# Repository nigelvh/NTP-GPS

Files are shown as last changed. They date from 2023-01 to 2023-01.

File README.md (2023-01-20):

# NTP-GPS
Custom GPS Hardware for use with NTP Stratum 1 servers, along with system configuration documentation.

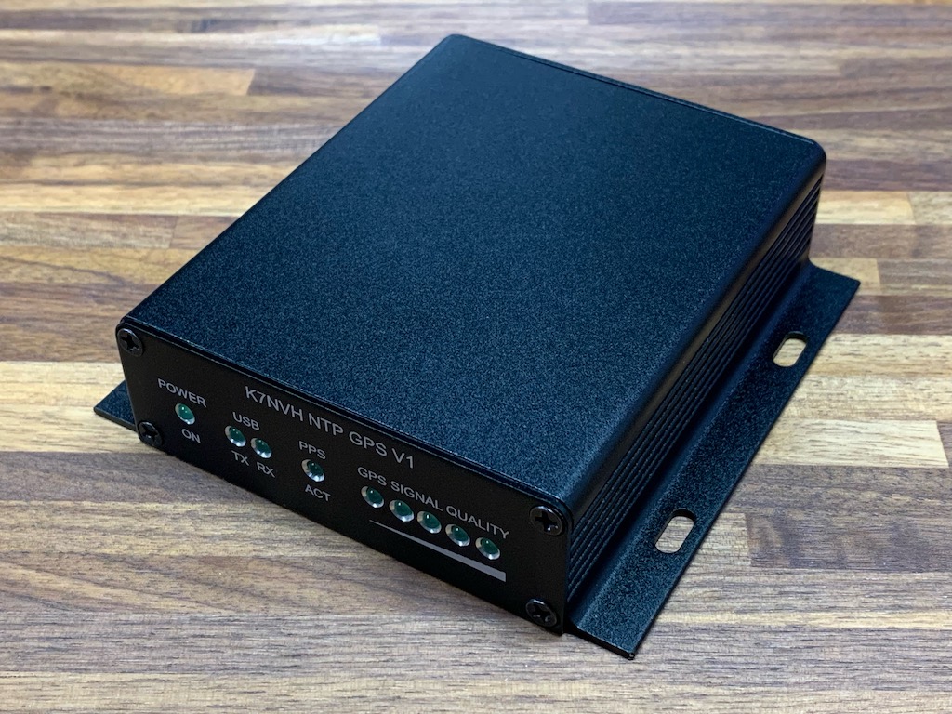
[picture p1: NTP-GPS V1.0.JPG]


## Hardware
The hardware designs for my specific device. There are many GPS options for building a Stratum 1 NTP server. This is just one take on it.

## Firmware
The firmware code and binaries for the device described in the Hardware section. Built in the Arduino IDE to be maximally approachable.

## Software
Configuration guides for setting up NTPd, NTPsec, or Chrony on Ubuntu, Debian, Alma, or Rocky to acquire the PPS signals provided by the GPS and use them to discipline the local clock and act as a Stratum 1 server.

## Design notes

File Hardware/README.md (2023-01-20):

# NTP GPS Hardware
This is a custom piece of hardware for use with stratum 1 NTP servers to provide a simple and flexible way of getting timing data into the NTP daemon of choice.

This is not a wholly unique device, there are other devices that perform similar functions or some subset thereof. It is certainly not the only way to accomplish the task. It was designed as a means to address the most common shortfalls I have seen and for the enjoyment of making it.

This device uses a good quality GPS receiver with precise Pulse Per Second (PPS) output, and exposes both the NMEA data, as well as the PPS signal on the DCD serial line over both USB (less precise timing) as well as RS232 (more precise timing) simultaneously. This is done to provide maximum flexibility to the user's use case. If a hardware serial port is available, use that as it will provide more precise timing. If only USB is available, that is also functional.

Many inexpensive off the shelf GPS receivers do not expose the PPS signals properly on the DCD serial line making precise timing difficult to capture, or expensive time servers are available which are double to many times the cost of this device. This device was designed to fit the middle ground of a quality time source for a use case where an existing server is available, and can be configured per the instructions in the Software folder of this repository.

The schematic and board files have been created in Eagle, though I cannot guarantee how they will load without all the the associated libraries. There are additionally exported images of the schematic and board designs available for reference without using the Eagle software package.

A parts text file has been included to cover some of the more important, or more specific parts for the design. It is not all inclusive (I didn't include the passives for example), but it covers the main components, as well as some useful accessories (cables, antenna, etc).

## Design Choices
### ESP32
The ESP32 was chosen as the microcontroller for this project as it is able to handle three simultaneous hardware UARTs, is reasonably inexpensive, and is easily programmed with the Arduino IDE. In some measures it is overkill for this application, but being inexpensive and easily programmable make it more approachable to more people.

### uBlox MAX-M8 GPS
The uBlox MAX-M8 GPS device was chosen for being a quality GPS chipset, that I am familiar with, and has good timing parameters. The MAX series is not the specifically timing oriented line, however it is more than accurate enough for NTP requirements. It is able to track multiple constellations and has good RF sensitivity. I have fitted it with the associated power circuitry to supply an active GPS antenna which is essential for longer runs of cable, which is likely to be required to span between a rooftop antenna placement and a server located inside a building/datacenter.

### FTDI UART and ST232 Serial Driver
There are microcontroller choices available that could do USB natively, as well as there are other RS232 driver chipsets that may be cheaper. These were chosen for being commonly available, widely used and proven, as well as having the required inputs/outputs to handle the PPS signal over the DCD line, which not all devices support.

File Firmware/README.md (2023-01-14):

# NTP GPS Firmware
This firmware is specific to the device described in the Hardware section. It is a simple Arduino sketch for the ESP32. The only required library is TinyGPSPlus, included in the libraries folder, though this copy does not track upstream and may be (and is likely) very out of date.

## Use one of the compiled binaries
Compiled binaries are available if you don't want to or are unable to use Arduino. They would be flashed to the board using esptool.

## Set up Arduino to work with ESP32
- Open the Arduino preferences pane, and add an `Additional Boards Manager URL` of `https://raw.githubusercontent.com/espressif/arduino-esp32/gh-pages/package_esp32_index.json`.
- Open `Tools -> Board -> Boards Manager`, search for "ESP32", and install the `esp32` package by Espressif Systems.
- Select the ESP32 parameters from the Tools Menu:
    - Board: ESP32 Dev Module
    - Flash Size: 4MB
    - PSRAM: Disabled
    - Port: <your_device_port>

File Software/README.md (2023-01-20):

# System Configuration
Configuration on various systems should look roughly similar, but example steps are provided for the OS's below. We will be using the classic NTPd daemon as the reference, but will also discuss Chrony and NTPsec.

These instructions assume that you have a GPS device that outputs NMEA data, as well as the PPS (Pulse Per Second) signal on the DCD pin of the hardware serial port `/dev/ttyS0`. If your device is on a different port, substitute that port into the configurations. If your device does not output the PPS signal, these instructions are not applicable.

- [Ubuntu 22.04 LTS and Debian 11 Bullseye](#ubuntu-2204-lts-and-debian-11-bullseye)
- [AlmaLinux 9.1 and Rocky Linux 9.1](#almalinux-91-and-rocky-linux-91)
- [Using Chrony](#using-chrony)
- [Using NTPsec](#using-ntpsec)

## Ubuntu 22.04 LTS and Debian 11 Bullseye
### Disable systemd-timesyncd
Ubuntu uses systemd-timesyncd which is a basic SNTP daemon and does not support disciplining or acting as a server for remote clients.
```bash
systemctl disable --now systemd-timesyncd
```
### Install packages
```bash
apt-get update
apt-get install pps-tools gpsd gpsd-clients
```
### Configure GPSd
GPSd will interface with the GPS module to parse the NMEA data for coarse time, and attach to the DCD signal as a PPS source. These data streams will be used to discipline the clock via NTPd's shared memory (SHM) interface.
```bash
curl -o /etc/default/gpsd https://raw.githubusercontent.com/nigelvh/NTP-GPS/main/Software/Files/gpsd.conf
systemctl enable gpsd
systemctl restart gpsd
```
### Verify GPSd is recieving the NMEA data and PPS signal
Use the utility `gpsmon` and look for NMEA sentences scrolling, as well as marks for the PPS offset every second. You might also use this opportunity to check the number of satellites being tracked.
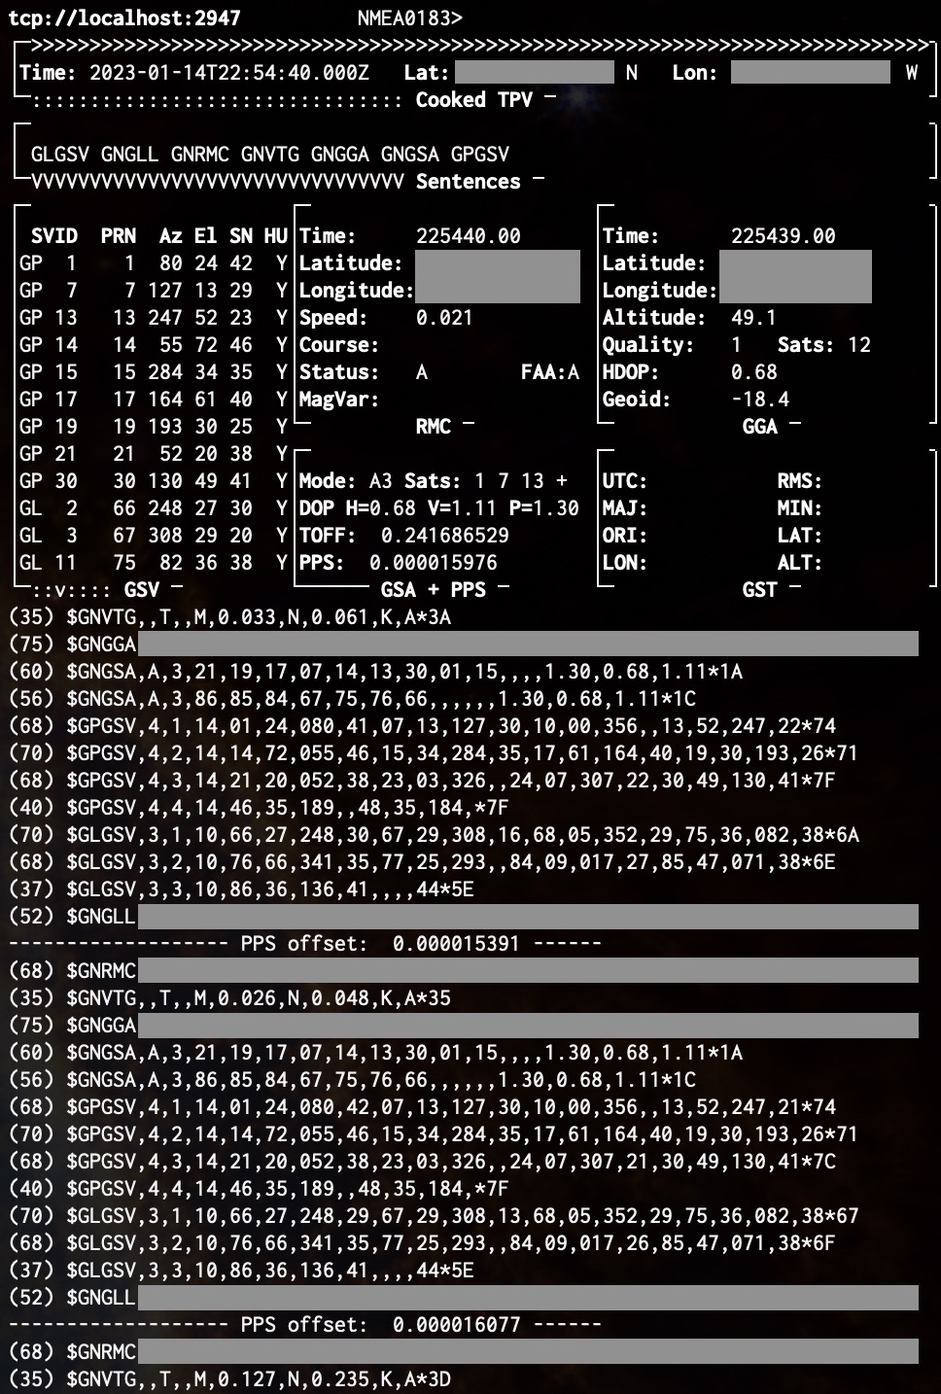
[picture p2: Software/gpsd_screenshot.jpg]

### Install NTPd
```bash
apt-get install ntp
```
### Tweak NTPd AppArmor Profile
The packaged apparmor profile (at the time of this writing) appears to be missing the openssl abstraction from the AppArmor profile, causing AppArmor deny messages to be found in the syslog. Comparing to the AppArmor profile from Debian and NTPsec, we just have to add one line to resolve it. However, the errors don't immediately appear to prevent NTPd from running.
```
test@test:~$ diff -c ~/usr.sbin.ntpd.orig /etc/apparmor.d/usr.sbin.ntpd
*** /home/test/usr.sbin.ntpd.orig	2023-01-14 06:55:32.058055004 +0000
--- /etc/apparmor.d/usr.sbin.ntpd	2023-01-14 06:56:01.138298034 +0000
***************
*** 16,21 ****
--- 16,22 ----
  /usr/sbin/ntpd flags=(attach_disconnected) {
    #include <abstractions/base>
    #include <abstractions/nameservice>
+   #include <abstractions/openssl>
    #include <abstractions/user-tmp>
  
    capability ipc_lock,
```
### Disable dhclient from overriding our NTP configuration
If dhclient is active or has been used on this system, it may override our NTP configuration.
```bash
sed -e "s/, ntp-servers//g" -i.backup /etc/dhcp/dhclient.conf
rm /etc/dhcp/dhclient-exit-hooks.d/ntp
rm /run/ntp.conf.dhcp
```
### Configure NTPd
NTPd will get the coarse time and PPS data via SHMs from GPSd. We'll need to include that in the NTPd configuration. This configuration otherwise is very close to defaults.
```bash
curl -o /etc/ntp.conf https://raw.githubusercontent.com/nigelvh/NTP-GPS/main/Software/Files/ntpd.conf
systemctl enable ntp
systemctl restart ntp
```
### Verify NTPd is getting the data
Query the NTP daemon to see what peers it is using. Look for the '*' next to the SHM(1) PPS peer.
```
test@test:~$ ntpq -c lpeers
     remote           refid      st t when poll reach   delay   offset  jitter
==============================================================================
 0.pool.ntp.org  .POOL.          16 p    -   64    0    0.000   +0.000   0.000
 1.pool.ntp.org  .POOL.          16 p    -   64    0    0.000   +0.000   0.000
*SHM(1)          .PPS.            0 l   40   64  377    0.000   +0.001   0.006
 SHM(0)          .GPS.           15 l   39   64  377    0.000  -242.60   0.727
-vps-7d02b399.vp 131.188.3.220    2 u   59  128  377  142.990   +0.647   1.257
+155.248.196.28  132.163.97.3     2 u   24   64  377   21.639   +1.285   0.580
+172.98.15.136   69.89.207.99     2 u   42   64  377   46.512   +0.900   0.223
-gotoro.hojmark. 97.183.206.88    2 u   48   64  377   58.146   +2.697   3.304
-clock.isc.org   5.200.6.34       3 u   35  128  377   21.762   -3.684   1.021
-66.85.78.80     172.16.23.153    2 u   53  128  377   50.980   -1.350   1.311
```
### Check that NTPd is reachable
Use `ntpdate -d <server_ip>` or configure NTPd on another host to use your new server, and verify that it is reachable. You're done!

## AlmaLinux 9.1 and Rocky Linux 9.1
Alma Linux defaults to using Chrony, so we'll use that as our example config.
### Install Packages
```bash
yum install epel-release
yum install gpsd gpsd-clients
```
### Configure GPSd
GPSd will interface with the GPS module to parse the NMEA data for coarse time, and attach to the DCD signal as a PPS source. These data streams will be used to discipline the clock via NTPd's shared memory (SHM) interface.
```bash
curl -o /etc/sysconfig/gpsd https://raw.githubusercontent.com/nigelvh/NTP-GPS/main/Software/Files/gpsd.conf
systemctl enable gpsd
systemctl restart gpsd
```
### Verify GPSd is recieving the NMEA data and PPS signal
Use the utility `gpsmon` and look for NMEA sentences scrolling, as well as marks for the PPS offset every second. You might also use this opportunity to check the number of satellites being tracked. Reference the screenshot from [Verify GPSd](#verify-gpsd-is-recieving-the-nmea-data-and-pps-signal) above for validating gpsmon output.
### Configure Chrony
Since Chrony is already installed by default, we just need to tweak the config.
```bash
curl -o /etc/chrony.conf https://raw.githubusercontent.com/nigelvh/NTP-GPS/main/Software/Files/chrony.conf
systemctl enable chronyd
systemctl restart chronyd
```
### Verify Chrony is tracking PPS
Verify chrony is tracking the PPS signal from GPSd with `chronyc sources` and `chronyc tracking`. Reference the [Using Chrony](#verify-chrony-is-tracking-pps-1) section for more detail and example output.

## Using Chrony
Setting up the system using Chrony will be very similar to using NTPd. Skip the configuring and verifying NTP steps above, and replace them with configuring and verifying Chrony here.

### Configure Chrony
Chrony will (like NTPd) get the coarse time and PPS data via SHMs from GPSd. We'll need to include that in the Chrony configuration. This configuration is otherwise very close to defaults.
```bash
apt-get install chrony
curl -o /etc/chrony/chrony.conf https://raw.githubusercontent.com/nigelvh/NTP-GPS/main/Software/Files/chrony.conf
systemctl enable chrony
systemctl restart chrony
```
### Verify Chrony is tracking PPS
Query the Chrony daemon to see what peers it is using. Look for the '*' next to the PPS peer.
```
test@test:~$ chronyc sources
MS Name/IP address         Stratum Poll Reach LastRx Last sample               
===============================================================================
#x GPS                          15   4   377    13   +247ms[ +247ms] +/-  200ms
#* PPS                           0   4   377    11    +69ns[ +104ns] +/-  436ns
^- ntp2.wiktel.com               1   9   377   154  +2514us[+2514us] +/-   21ms
^- li1150-42.members.linode>     2   9   377   147   +763us[ +763us] +/-   69ms
^- gosanf.hojmark.net            2   9   377    31  -1058us[-1058us] +/-   46ms
^- 44.190.40.123                 2   9   377   155   -889us[ -889us] +/-   33ms
```
We can also see more details about the server state. Such as that we're tracking the PPS reference, and operating as a Stratum 1, as well as a number of timing related parameters.
```
test@test:~$ chronyc tracking
Reference ID    : 50505300 (PPS)
Stratum         : 1
Ref time (UTC)  : Sun Jan 15 04:40:55 2023
System time     : 0.000000047 seconds slow of NTP time
Last offset     : -0.000000040 seconds
RMS offset      : 0.000000484 seconds
Frequency       : 7.842 ppm slow
Residual freq   : +0.003 ppm
Skew            : 0.023 ppm
Root delay      : 0.000000001 seconds
Root dispersion : 0.000023089 seconds
Update interval : 16.0 seconds
Leap status     : Normal
```
### Check that NTPd is reachable
Use `ntpdate -d <server_ip>` or configure NTPd on another host to use your new server, and verify that it is reachable. You're done!

## Using NTPsec
NTPsec configuration will look very similar to the NTPd configuration. Skip the configuring and verifying NTP steps above, and replace them with configuring and verifying NTPsec here.

### Configure NTPsec
```bash
apt-get install NTPsec
rm /etc/dhcp/dhclient-exit-hooks.d/ntpsec 
rm /run/ntpsec/ntp.conf.dhcp
curl -o /etc/ntpsec/ntp.conf https://raw.githubusercontent.com/nigelvh/NTP-GPS/main/Software/Files/ntpsec.conf
systemctl enable ntpsec
systemctl restart ntpsec
```
### Verify NTPsec is tracking PPS
Query the NTPsec daemon to see what peers it is using. This matches the command syntax as NTPd. Look for the '*' next to the SHM(1) PPS peer.
```
test@test:~$ ntpq -c lpeers
     remote                                   refid      st t when poll reach   delay   offset   jitter
=======================================================================================================
*SHM(1)                                  .PPS.            0 l   28   64  377   0.0000  -0.0194   1.2577
 SHM(0)                                  .GPS.           15 l   27   64  377   0.0000 -243.975   2.8552
 0.pool.ntp.org                          .POOL.          16 p    -  256    0   0.0000   0.0000   0.0001
 1.pool.ntp.org                          .POOL.          16 p    -  256    0   0.0000   0.0000   0.0001
-rn5.quickhost.hk                        45.79.13.206     3 u   58   64  377  29.5838   6.9985   1.9140
-h69.41.139.40.ip.windstream.net         .GPS.            1 u  128   64   16  82.7081   5.4127   1.0102
+208.67.72.50                            17.253.2.123     2 u   63   64  377  76.8092   0.2502   1.1300
-38.17.55.196                            86.77.84.80      5 u   55   64  177  51.7627   8.4964   5.5212
+c-73-14-129-213.hsd1.co.comcast.net     .PPS.            1 u   55   64  377  42.2095  -0.5344   0.8669
-108.61.73.244                           128.59.0.245     2 u   58   64  377  60.4326   2.3897   1.4830
-50-203-248-23-static.hfc.comcastbusines 130.207.244.240  2 u  123   64    6  79.1322  -2.3248   0.1393
```

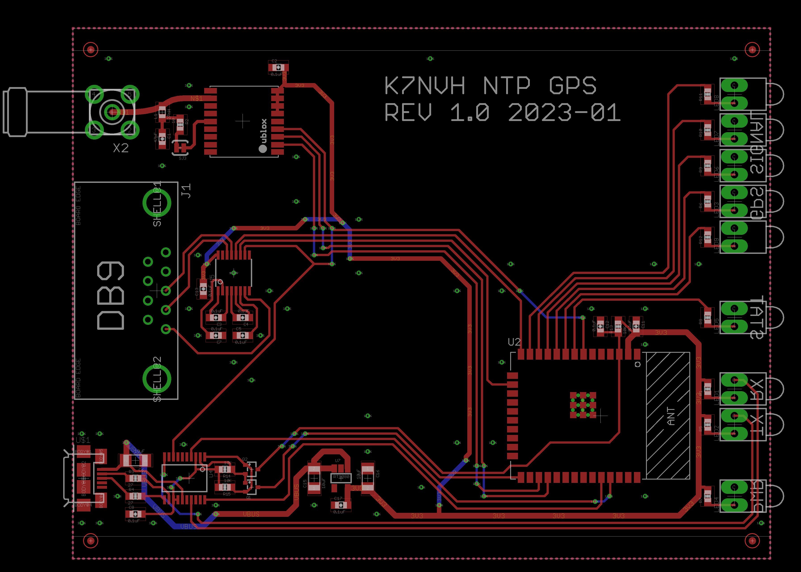
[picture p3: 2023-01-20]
Hardware/Image_Board_V1.0_withoutPours.png

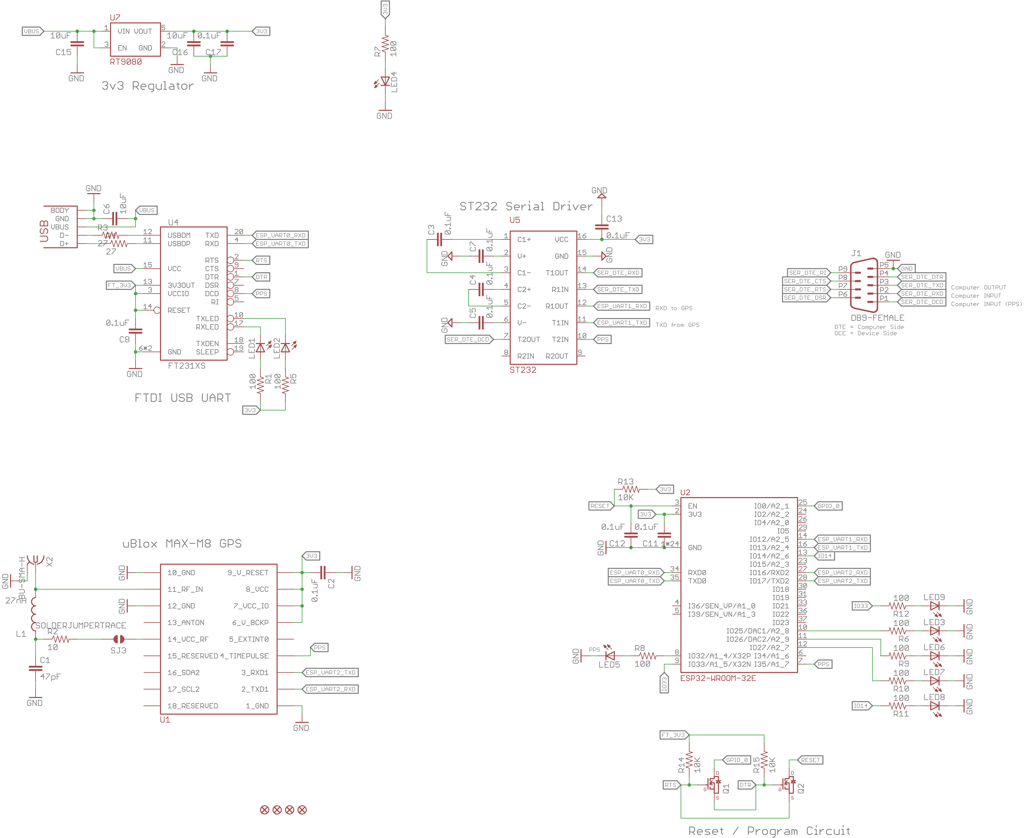
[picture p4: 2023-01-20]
Hardware/Image_Schematic_V1.0.png

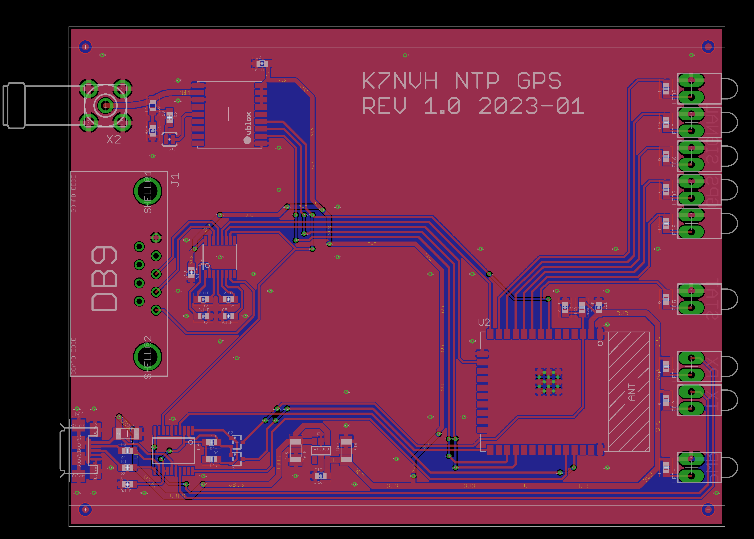
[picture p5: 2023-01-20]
Hardware/Image_Board_V1.0_withPours.png

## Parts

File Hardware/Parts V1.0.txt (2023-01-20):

RS232 Driver
	ST3232BTR
	https://www.digikey.com/en/products/detail/stmicroelectronics/ST3232BTR/1039246

FTDI UART
	FT231XS
	https://www.digikey.com/en/products/detail/ftdi-future-technology-devices-international-ltd/FT231XS-R/3029139

DB9 Connector
	https://www.digikey.com/en/products/detail/amphenol-cs-fci/D09S13B4GV00LF/1537562

USB Connector
	https://www.digikey.com/en/products/detail/amphenol-cs-fci/10118192-0001LF/2785387

Case
	https://www.digikey.com/en/products/detail/bud-industries/EXT-9165/5291613

ESP32
	https://www.digikey.com/en/products/detail/espressif-systems/ESP32-WROOM-32UE-N4/11613136

3V3 Regulator
	https://www.digikey.com/en/products/detail/richtek-usa-inc/RT9080-33GJ5/6161634

LEDs
	Orange: https://www.digikey.com/en/products/detail/qt-brightek-qtb/QBL7OA80D-MP4A/6556228
	Green: https://www.digikey.com/en/products/detail/qt-brightek-qtb/QBL7YG80D-MP4A/6556230
	Red: https://www.digikey.com/en/products/detail/qt-brightek-qtb/QBL7SA80D-MP4A/6556227

SMA Connector
	https://www.digikey.com/en/products/detail/adam-tech/RF2-49B-T-00-50-G-HDW/9831420

GPS
	https://www.digikey.com/en/products/detail/u-blox/MAX-M8C-0/6150635

Reset Circuit Mosfets
	https://www.digikey.com/en/products/detail/diodes-incorporated/DMN61D9UWQ-13/7666847
	
Serial Cable
	https://www.amazon.com/StarTech-com-Black-Straight-Through-Serial/dp/B00A6GIUZA/

USB Cable
	https://www.amazon.com/Monoprice-Select-Micro-Charge-Cable/dp/B018RAW1FG/

GPS Antenna (SMA-M)
	https://www.digikey.com/en/products/detail/abracon-llc/APAMPG-130/5226441

SMA Barrel (SMA-F to SMA-F)
	https://www.digikey.com/en/products/detail/linx-technologies-inc/ADP-SMAF-SMAF/1577233

LMR-240 Cables (SMA-M to SMA-M)
	 5M - https://www.digikey.com/en/products/detail/mcgill-microwave-systems/LMR-240-SM-SM-QTY-5m/17373752
	10M - https://www.digikey.com/en/products/detail/mcgill-microwave-systems/LMR-240-SM-SM-QTY-10m/17372956
	15M - https://www.digikey.com/en/products/detail/mcgill-microwave-systems/LMR-240-SM-SM-QTY-15m/17374008
	20M - https://www.digikey.com/en/products/detail/mcgill-microwave-systems/LMR-240-SM-SM-QTY-20m/17373204
	25M - https://www.digikey.com/en/products/detail/mcgill-microwave-systems/LMR-240-SM-SM-QTY-25m/17373543
	30M - https://www.digikey.com/en/products/detail/mcgill-microwave-systems/LMR-240-SM-SM-QTY-30m/17373414

SMA Lightning Arrestor
	https://www.amazon.com/Lightning-Arrestor-Protector-Bulkhead-Connector/dp/B07K24RTCW

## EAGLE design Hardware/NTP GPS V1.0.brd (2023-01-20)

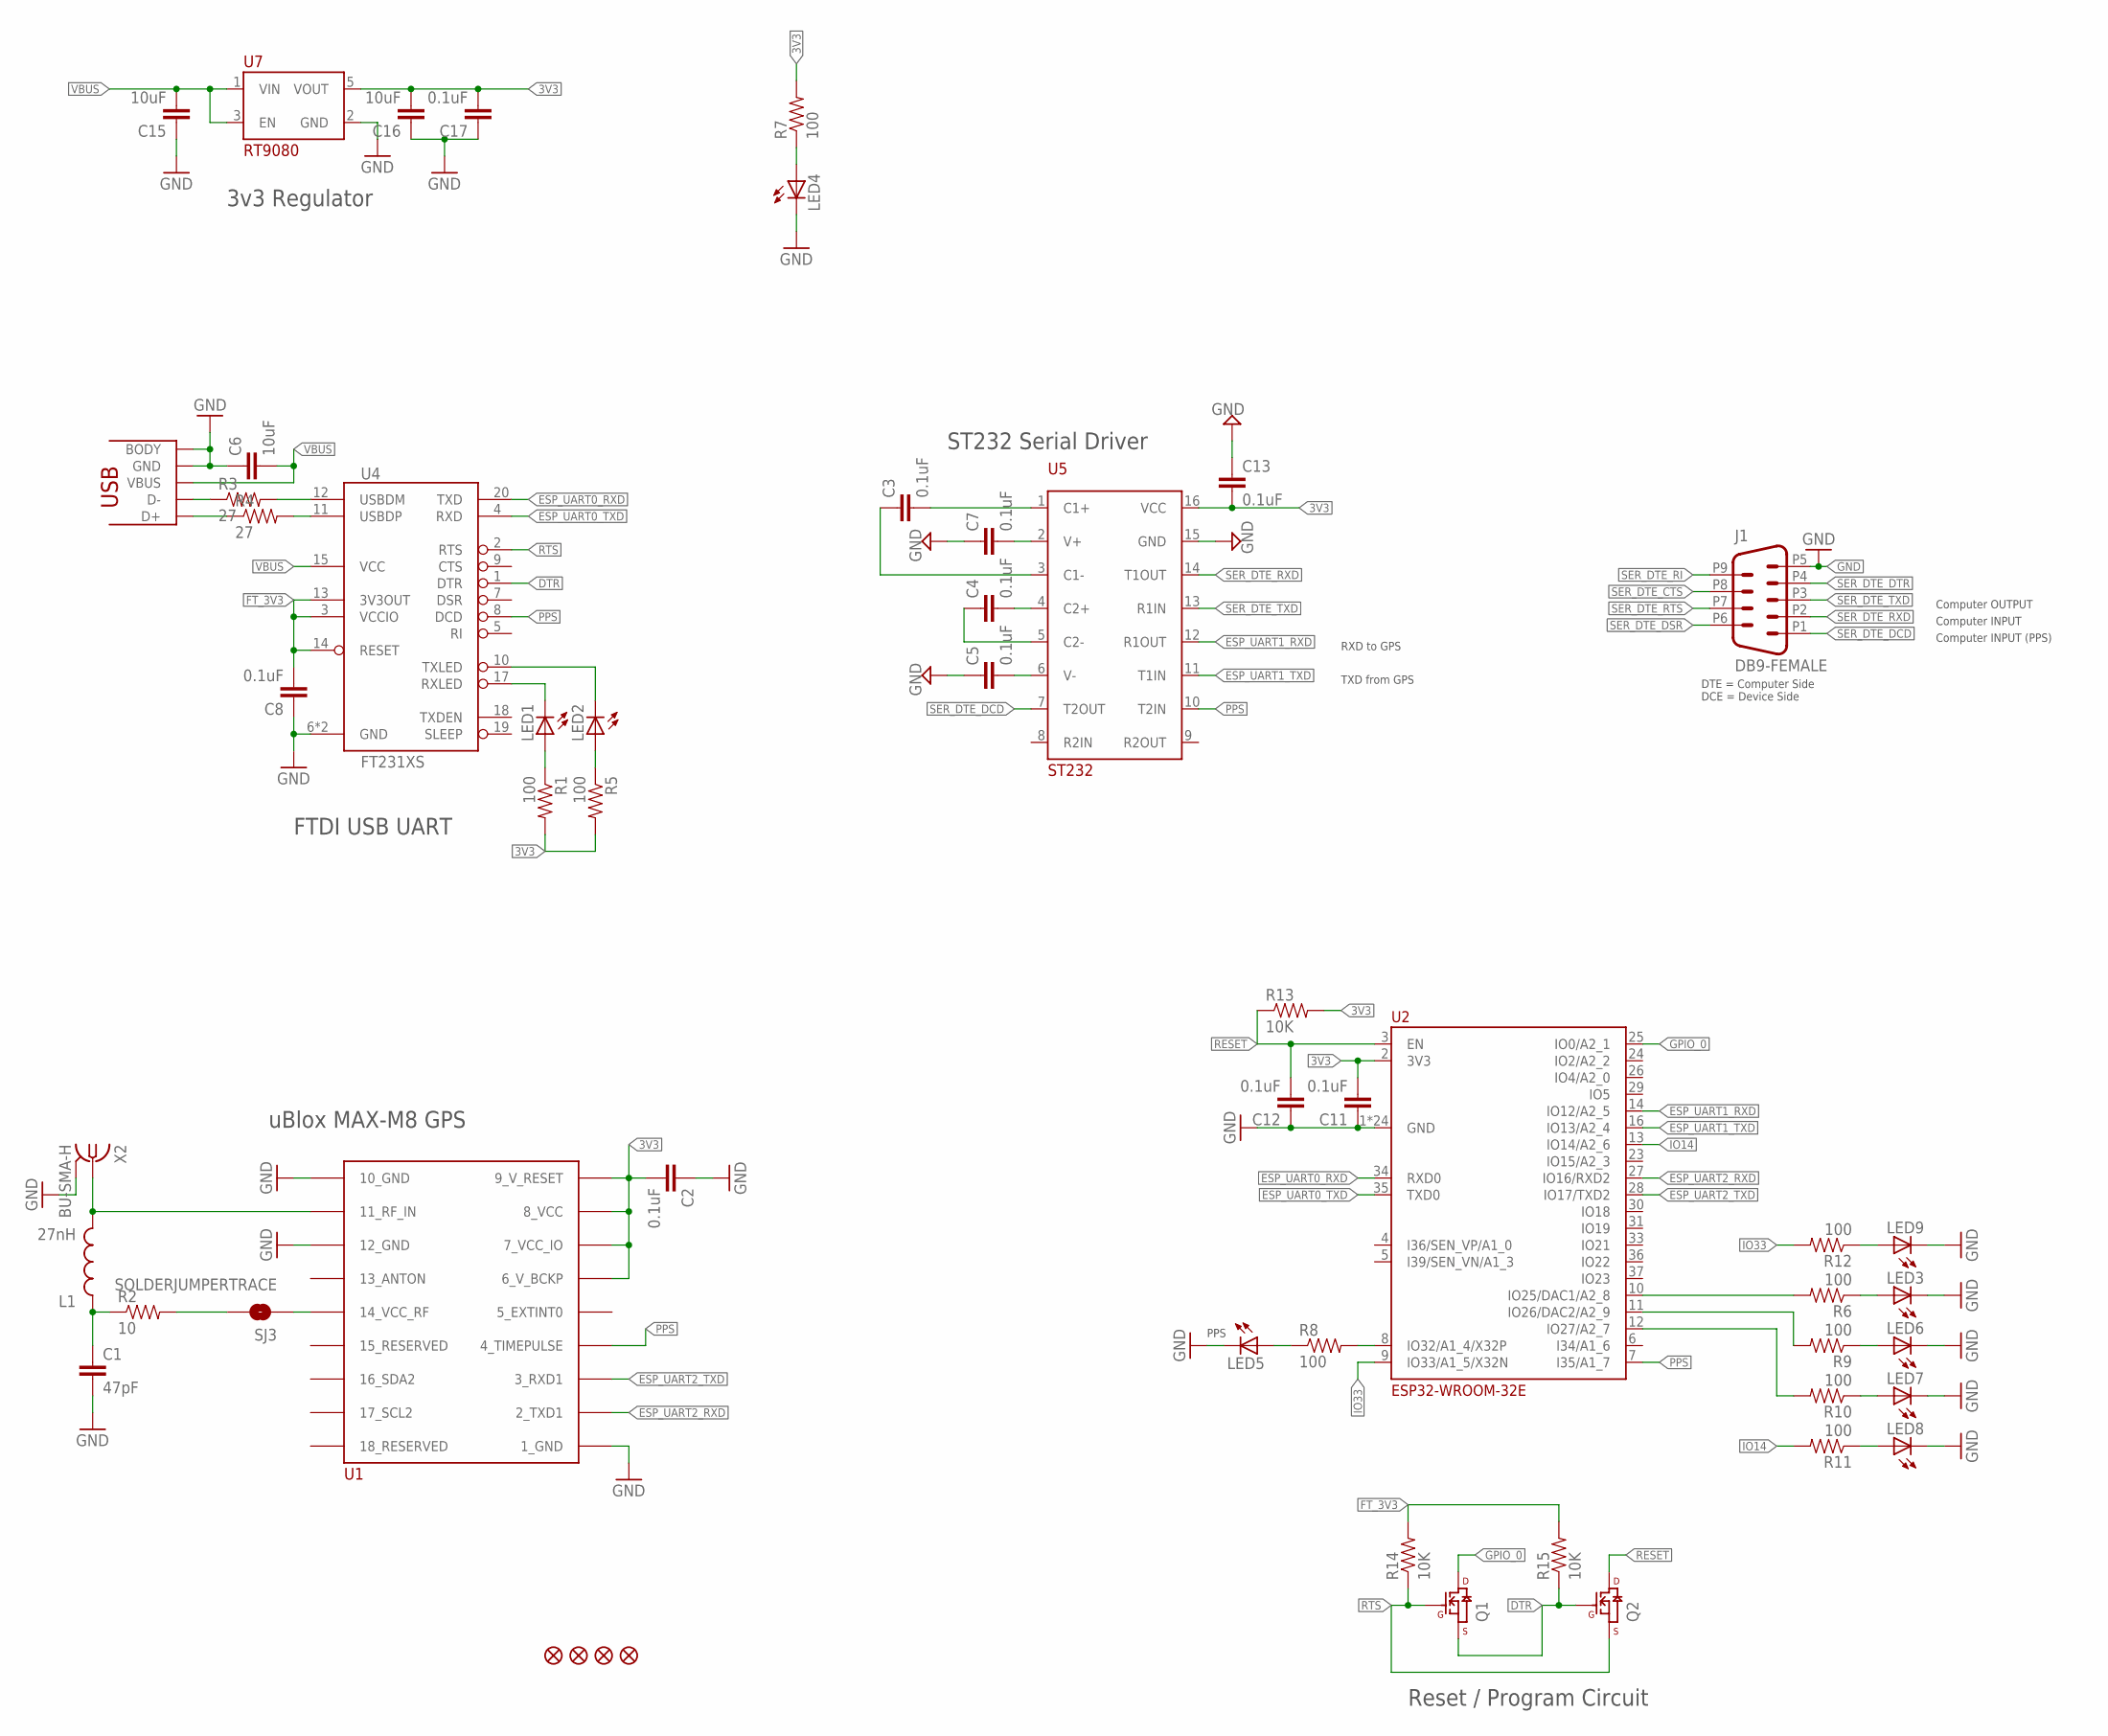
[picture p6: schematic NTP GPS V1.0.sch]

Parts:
C1: 47pF; 0603-CAP
C2, C3, C4, C5, C7, C8, C11, C12, C13, C17: 0.1uF; 0603-CAP
C6, C15, C16: 10uF; 1206
FID1, FID2, FID3, FID4: FIDUCIAL
J1: DB9-FEMALE; AMP_DELTAD_D09S13B4GV00LF
L1: 27nH; 0603
LED1, LED2, LED3, LED4, LED5, LED6, LED7, LED8, LED9: LED; LED_QBL7XX80D-MP4A
Q1, Q2: MOSFET_N_CHANNELSI1308; SC-70-3
R1, R5, R6, R7, R8, R9, R10, R11, R12: 100; 0603-RES
R2: 10; 0603-RES
R3, R4: 27; 0603-RES
R13, R14, R15: 10K; 0603-RES
SJ3: SOLDERJUMPERTRACE; SJ_2S-TRACE
U1: UBLOX_MAX
U2: ESP32-WROOM-32E
U4: FT231XS; SSOP-20
U5: ST232; SSOP-16
U7: RT9080; SOT-23-5
U$1: USB-MICROB; USB-MICROB-10118192
X2: BU-SMA-H

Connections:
3V3: C2.2, C11.2, C13.2, C16.2, C17.2, R1.2, R5.2, R7.2, R13.2, U1.6_V_BCKP, U1.7_VCC_IO, U1.8_VCC, U1.9_V_RESET, U2.2 (3V3), U5.16 (VCC), U7.5 (VOUT)
DTR: Q1.P$2 (S), Q2.P$1 (G), R15.1, U4.1 (DTR)
ESP_UART0_RXD: U2.34 (RXD0), U4.20 (TXD)
ESP_UART0_TXD: U2.35 (TXD0), U4.4 (RXD)
ESP_UART1_RXD: U2.14 (IO12/A2_5), U5.12 (R1OUT)
ESP_UART1_TXD: U2.16 (IO13/A2_4), U5.11 (T1IN)
ESP_UART2_RXD: U1.2_TXD1, U2.27 (IO16/RXD2)
ESP_UART2_TXD: U1.3_RXD1, U2.28 (IO17/TXD2)
FT_3V3: C8.2, R14.2, R15.2, U4.3 (VCCIO), U4.13 (3V3OUT), U4.14 (RESET)
GND: C1.2, C2.1, C5.1, C6.1, C7.1, C8.1, C11.1, C12.1, C13.1, C15.1, C16.1, C17.1, J1.P5 (5), LED3.C, LED4.C, LED5.C, LED6.C, LED7.C, LED8.C, LED9.C, U1.1_GND, U1.10_GND, U1.12_GND, U2.1 (GND), U2.15 (GND), U2.38 (GND), U2.P$1 (GND), U2.P$2 (GND), U2.P$3 (GND), U2.P$4 (GND), U2.P$5 (GND), U2.P$6 (GND), U2.P$7 (GND), U2.P$8 (GND), U2.P$9 (GND), U2.P$10 (GND), U2.P$11 (GND), U2.P$12 (GND), U2.PAD@1 (GND), U2.PAD@2 (GND), U2.PAD@3 (GND), U2.PAD@4 (GND), U2.PAD@5 (GND), U2.PAD@6 (GND), U2.PAD@7 (GND), U2.PAD@8 (GND), U2.PAD@9 (GND), U4.6 (GND), U4.16 (GND), U5.15 (GND), U7.2 (GND), U$1.5 (GND), U$1.BODY@1 (BODY), U$1.BODY@2 (BODY), U$1.BODY@3 (BODY), U$1.BODY@4 (BODY), U$1.BODY@5 (BODY), U$1.BODY@6 (BODY), X2.2, X2.3 (2), X2.4 (2), X2.5 (2)
GPIO_0: Q1.P$3 (D), U2.25 (IO0/A2_1)
IO14: R11.2, U2.13 (IO14/A2_6)
IO33: R12.2, U2.9 (IO33/A1_5/X32N)
unnamed: L1.2, U1.11_RF_IN, X2.1
unnamed: R8.2, U2.8 (IO32/A1_4/X32P)
unnamed: SJ3.1, U1.14_VCC_RF
unnamed: C1.1, L1.1, R2.1
unnamed: C7.2, U5.2 (V+)
unnamed: C5.2, U5.6 (V-)
unnamed: R3.1, U$1.2 (D-)
unnamed: R4.1, U$1.3 (D+)
unnamed: LED2.A, R5.1
unnamed: C3.2, U5.1 (C1+)
unnamed: LED3.A, R6.1
unnamed: C4.2, U5.4 (C2+)
unnamed: LED1.C, U4.17 (RXLED)
unnamed: C3.1, U5.3 (C1-)
unnamed: C4.1, U5.5 (C2-)
unnamed: LED2.C, U4.10 (TXLED)
unnamed: R4.2, U4.11 (USBDP)
unnamed: R3.2, U4.12 (USBDM)
unnamed: R2.2, SJ3.2
unnamed: LED4.A, R7.1
unnamed: LED5.A, R8.1
unnamed: LED1.A, R1.1
unnamed: LED6.A, R9.1
unnamed: LED7.A, R10.1
unnamed: LED8.A, R11.1
unnamed: LED9.A, R12.1
unnamed: R6.2, U2.10 (IO25/DAC1/A2_8)
unnamed: R9.2, U2.11 (IO26/DAC2/A2_9)
unnamed: R10.2, U2.12 (IO27/A2_7)
PPS: U1.4_TIMEPULSE, U2.7 (I35/A1_7), U4.8 (DCD), U5.10 (T2IN)
RESET: C12.2, Q2.P$3 (D), R13.1, U2.3 (EN)
RTS: Q1.P$1 (G), Q2.P$2 (S), R14.1, U4.2 (RTS)
SER_DTE_CTS: J1.P8 (8)
SER_DTE_DCD: J1.P1 (1), U5.7 (T2OUT)
SER_DTE_DSR: J1.P6 (6)
SER_DTE_DTR: J1.P4 (4)
SER_DTE_RI: J1.P9 (9)
SER_DTE_RTS: J1.P7 (7)
SER_DTE_RXD: J1.P2 (2), U5.14 (T1OUT)
SER_DTE_TXD: J1.P3 (3), U5.13 (R1IN)
VBUS: C6.2, C15.2, U4.15 (VCC), U7.1 (VIN), U7.3 (EN), U$1.1 (VBUS)

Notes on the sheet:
FTDI USB UART
DTE = Computer Side DCE = Device Side
Computer INPUT
Computer OUTPUT
Computer INPUT (PPS)
TXD from GPS
RXD to GPS
3v3 Regulator
Reset / Program Circuit
PPS
ST232 Serial Driver
uBlox MAX-M8 GPS

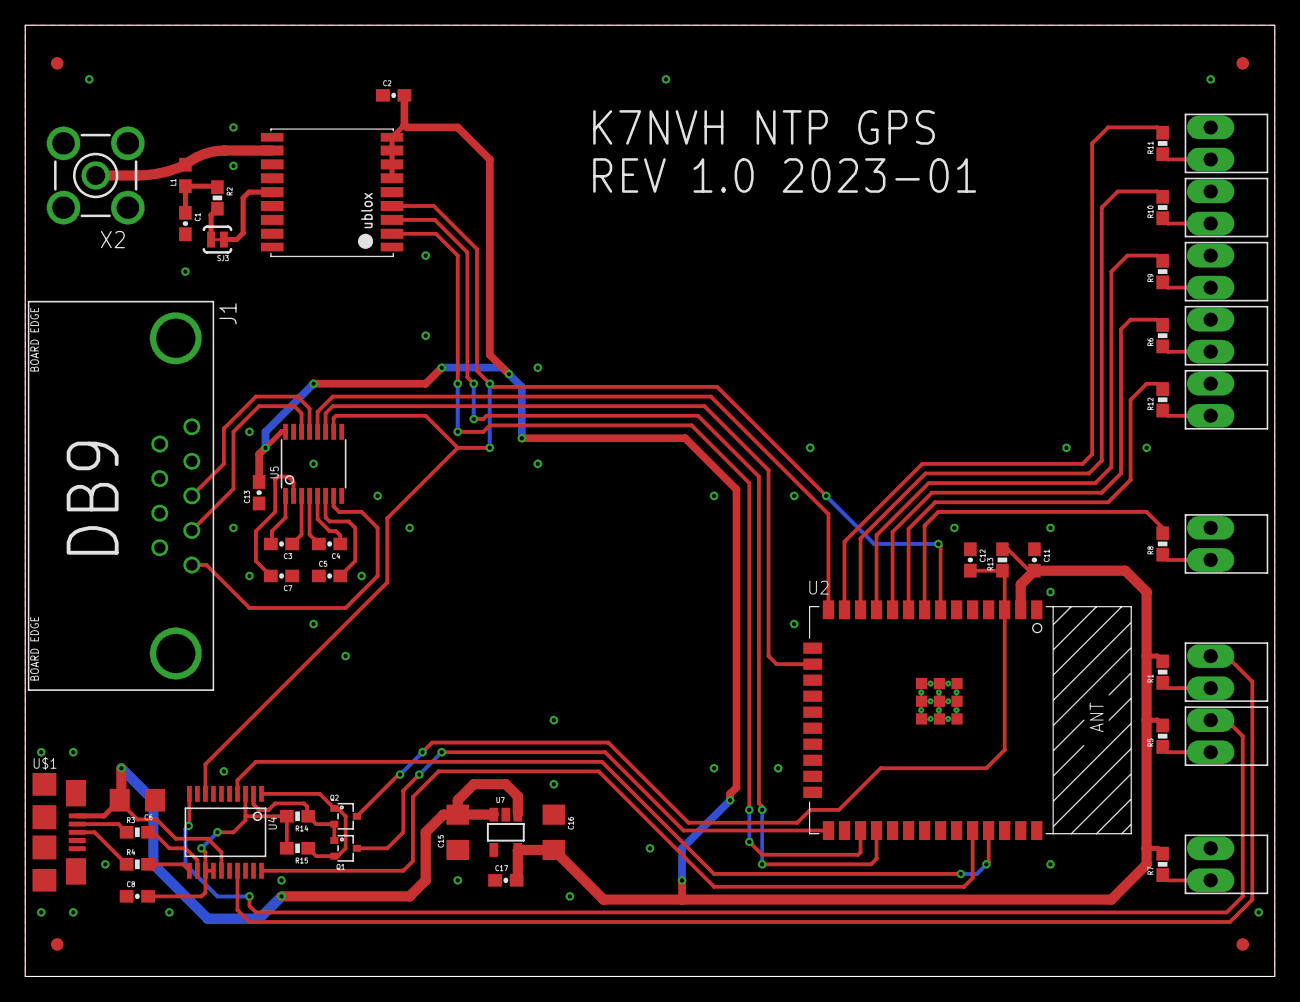
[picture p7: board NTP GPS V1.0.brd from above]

Board: 2 copper layers, 99.1 x 75.4 mm, 54 parts (0 on the bottom side), 49 nets.

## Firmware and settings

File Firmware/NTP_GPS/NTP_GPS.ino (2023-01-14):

#include <TinyGPSPlus.h>
#include <TinyGPS++.h>

String SW_VERS = "1.00";
String SW_VERS_NAME = "\n\n\n\nK7NVH NTP GPS - SW Vers " + SW_VERS + "\n\n\n\n";

#define LED_GPS_1 33
#define LED_GPS_2 25
#define LED_GPS_3 26
#define LED_GPS_4 27
#define LED_GPS_5 14

#define LED_STAT 32

#define SER_GPS_TX 17
#define SER_GPS_RX 16
#define SER_USB_TX 1
#define SER_USB_RX 3
#define SER_232_TX 13
#define SER_232_RX 12

#define PPS_INPUT 35

TinyGPSPlus gps;
float f_lat, f_lon;
long alt;
byte hour, minute, second, num_sats, fix_type;

byte flag_gps_output_usb = 1;
byte flag_gps_output_232 = 1;
volatile byte flag_pps_isr = 0;

unsigned long timestamp_last_pps = 0;
unsigned long pps_lock_time = 0;
unsigned long pps_lock_rsts = 0;

byte gps_read_byte = 0;

void IRAM_ATTR pps_isr() {
  unsigned long time_now = millis();
  if(timestamp_last_pps != 0) { // Don't throw an error if we just started up

    // Catch if the PPS is outside of the expected range
    if((time_now - timestamp_last_pps < 900) || (millis() - timestamp_last_pps > 1100)) {
      // ALERT - Got PPS signal at unexpected time! 
      //Serial.print("Time difference: ");
      //Serial.print(time_now - timestamp_last_pps);
      //Serial.println("ms.");
      
      timestamp_last_pps = time_now; // Mark this as the latest timestamp for a PPS pulse for next time around
      pps_lock_time = 0; // Reset the seconds counter for how long we've recieved a continuous valid train of PPS pulses
      pps_lock_rsts++; // Increment the lock resets counter
      return;
    }

    timestamp_last_pps = time_now; // Mark this as the latest timestamp for a PPS pulse for next time around
    pps_lock_time++; // Increment the seconds counter for how long we've recieved a continuous valid train of PPS pulses
  } else { // We've just started up, just set the timestamp for this PPS pulse
    timestamp_last_pps = time_now;
  }

  flag_pps_isr = 1;
}

// Startup setup items
void setup() {
  // Configure the serial ports
  Serial.begin(9600, SERIAL_8N1, SER_USB_RX, SER_USB_TX); // The USB Serial Port
  Serial1.begin(9600, SERIAL_8N1, SER_232_RX, SER_232_TX); // The RS232 Serial Port
  Serial2.begin(9600, SERIAL_8N1, SER_GPS_RX, SER_GPS_TX); // The TTL Serial Port to the GPS Module

  // Configure the GPS status LEDs
  pinMode(LED_GPS_1, OUTPUT); // The leftmost
  pinMode(LED_GPS_2, OUTPUT);
  pinMode(LED_GPS_3, OUTPUT);
  pinMode(LED_GPS_4, OUTPUT);
  pinMode(LED_GPS_5, OUTPUT); // The rightmost

  // Configure the status LED
  pinMode(LED_STAT, OUTPUT);

  // Attach an interrupt to the PPS input pin
  attachInterrupt(PPS_INPUT, pps_isr, RISING);

  delay(1000);
  Serial.println(SW_VERS_NAME);
  Serial1.println(SW_VERS_NAME);
  delay(2000);
  while(Serial2.available()) Serial2.read(); // Clear out any garbage from the input buffer from the GPS
}

// Main loop
void loop() {
  // Read from the GPS and output to the USB and RS232 ports (if enabled)
  if(Serial2.available()) {
    gps_read_byte = Serial2.read();
    if(flag_gps_output_usb) Serial.write(gps_read_byte);
    if(flag_gps_output_232) Serial1.write(gps_read_byte);

    gps.encode(gps_read_byte);
  }

  // Run some stuff every second when we get the PPS interrupt
  if (flag_pps_isr) {
    flag_pps_isr = 0;

    // Send our custom strings. The PPS signal should come through roughly ~100ms before the GPS NMEA data comes
    // But make sure the last byte we got from the GPS was the newline, so we're not dumping our string in the middle of another
    if (gps_read_byte == 10) send_custom_nmea();

    set_gps_leds((byte)gps.satellites.value());
    digitalWrite(LED_STAT, !digitalRead(LED_STAT));
  }

  // Read from the USB and RS232 ports and maybe do something
}

// Update the GPS LEDs based on the number of satellites we have
void set_gps_leds(byte num_sats) {
  if (num_sats > 11){ digitalWrite(LED_GPS_5, HIGH); }else{ digitalWrite(LED_GPS_5, LOW); }
  if (num_sats > 9){ digitalWrite(LED_GPS_4, HIGH); }else{ digitalWrite(LED_GPS_4, LOW); }
  if (num_sats > 7){ digitalWrite(LED_GPS_3, HIGH); }else{ digitalWrite(LED_GPS_3, LOW); }
  if (num_sats > 5){ digitalWrite(LED_GPS_2, HIGH); }else{ digitalWrite(LED_GPS_2, LOW); }
  if (num_sats > 3){ digitalWrite(LED_GPS_1, HIGH); }else{ digitalWrite(LED_GPS_1, LOW); }
}

// Send custom NMEA string(s)
void send_custom_nmea() {
  String str_start = "$";
  String str_stop = "*";
  String custom = "NVDBG," + String(pps_lock_time, DEC) + "," + String(pps_lock_rsts, DEC) + "," + SW_VERS;
  byte checksum = 0;

  // Calculate the string's checksum
  for (uint8_t i = 0; i < custom.length(); i++) {
    checksum = checksum ^ custom[i];
  }
  String str_checksum = String(checksum, HEX);
  str_checksum.toUpperCase();

  String str_final = str_start + custom + str_stop + str_checksum;
  
  Serial.println(str_final);
  Serial1.println(str_final);
}

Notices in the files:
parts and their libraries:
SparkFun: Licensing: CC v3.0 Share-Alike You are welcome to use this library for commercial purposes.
